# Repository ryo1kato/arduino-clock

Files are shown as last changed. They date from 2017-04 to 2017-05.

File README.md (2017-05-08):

## Arduino Blink "minute repeater" Clock (ATtiny85 version)

A clock with blinking LED indicating the time of day. &nbsp;
LED version of a [repeater](https://en.wikipedia.org/wiki/Repeater_%28horology%29)
You can tell a time in the dark, from distance, w/o glasses. &nbsp;
Useful if you're myopic and don't have glasses or smartphone within reach of your hand when you're in the bed (like me, with my two kids blocking my both sides). &nbsp;
LED brightness is automatically adjusted with light sensor (CdS photo cell)
The design uses AVR ATtiny85 micro controller and DS3231 RTC chip with "smart" RGB LED WS2812B.

## Telling Time
* Blinking in white: base hour of 0, 3, 6, or 9 o'clock.
    - once        : 0 o'clock
    - twice       : 3 o'clock
    - three times : 6 o'clock
    - four times  : 9 o'clock

* Blinking in <span style='color: #00AA00'>**green**</span>: add one or two hours to the above base hour.
    - example: blinking in white for three times, and then twice in green indicates 8 o'clock (8am or 8pm)

* Blinking in <span style='color: red'>**red**</span>: 10 minutes per blink.
    - example: blinking in red for four times: 40 minutes

* Blinking in <span style='color: blue'>**blue**</span>(fast): one minute per blink.

The clock blinks in white -> green -> blue -> blue, skipping some of the colors, for example, skipping red if the time is 10:02 (in which case it blinks in whilte three times, in green once, skips green, and in blue twice)

After completing this cycle, clock sleeps about 3 seconds and start a new cycle.

### Adjusting Time
Long press *Hour* and/or *Minute* button until they start blinking slowly in max brightness.

* Long press *Hour* button : advance time by 60 minutes (blinks in green)
* Long press *Minute* button : advance time by one minutes (blinks in blue)
* Long press **both** buttons : advance time by ten minutes (blinks in red)

You need to keep the buttons pressed and wait for an time indicating cycle to complete, until it starts blinking slowly and brightly.

### Build of Materials
* PCB
    - SMD (rev 0.5.1) [OSH Park](https://oshpark.com/shared_projects/CKZP3omf)
    - THT (rev 0.2) [OSH Park](https://oshpark.com/shared_projects/mC1U04Ox)
* BOM: [bom.txt](schematic/bom.txt)

### Port Assignment
* RST (GPIO #5) - Hour & Minute Buttons (using ADC above 2.2v reset threshold)
* GPIO #0       -  I2C SDA to RTC
* GPIO #1       -  Smart LED NeoPixel WS2812B
* GPIO #2       -  I2C SCL to RTC
* GPIO #3       -  Photo Cell
* GPIO #4       -  Power Control for LED, RTC, Photo Cell

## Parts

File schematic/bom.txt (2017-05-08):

BOM for SMD version (rev 0.5.1) of the board: https://oshpark.com/shared_projects/CKZP3omf
There's an THT version of the board too. https://oshpark.com/shared_projects/mC1U04Ox - Simply chagne C and R to THT versions.

Digi-Key Cart: http://www.digikey.com/short/3nb1p4 (Except WS2812B LED)

SW3   Minute       Panasonic Electronic Components EVQ-PE104K
U1    ATTiny85     ATTINY85-20PU-ND (DIP8)
R2    PHOTO CELL   Photo resister 10~100k ohm @ 10lux
R3    R_ADC        0805(2012 metric) 4.7K ohm, or adjust resistance based on photo cell resistance characteristic
SW2   Hour         Panasonic Electronic Components EVQ-PE104K
R4    10K          0805(2012 metric)
U2    DS3231       DS3231SN (SOIC-16W)
BT1   Battery      Keystone 36-2479-ND
R6    5K           0805(2012 metric) 5K ohm (4.7K ohm works as well)
R5    2K           0805(2012 metric) 2K ohm
J2    WS2812B_OUT  Pin_Headers:Pin_Header_Straight_1x03
J1    ICSP         Pin_Headers:Pin_Header_Straight_2x03
U3    MCP1700T     MCP1700T-3302E/MB (SOT89)
C2    1uF          0805(2012 metric)
C1    1uF          0805(2012 metric)
J3    I2C          Pin_Headers:Pin_Header_Straight_1x04
R7    SCL_PUP      0805(2012 metric) 4.7K ohm
R1    SDA_PUP      0805(2012 metric) 4.7K ohm
LED1  WS2812       WS2812-8mm: Designed for  https://www.adafruit.com/product/1734, but only tested with https://www.amazon.com/dp/B01D1FFVOA
C4    0.1uF        0805(2012 metric)
C5    0.1uF        0805(2012 metric)
C6    0.1uF        0805(2012 metric)
C3    0.1uF (LED)  0805(2012 metric) for WS2812B. You don’t need this when using https://www.amazon.com/dp/B01D1FFVOA

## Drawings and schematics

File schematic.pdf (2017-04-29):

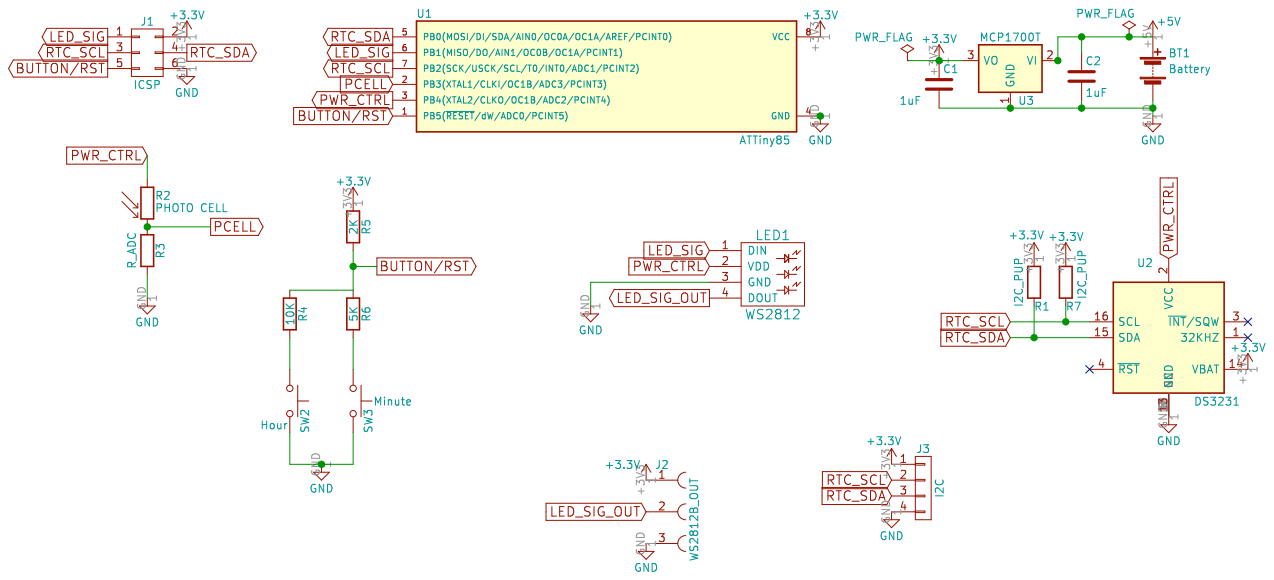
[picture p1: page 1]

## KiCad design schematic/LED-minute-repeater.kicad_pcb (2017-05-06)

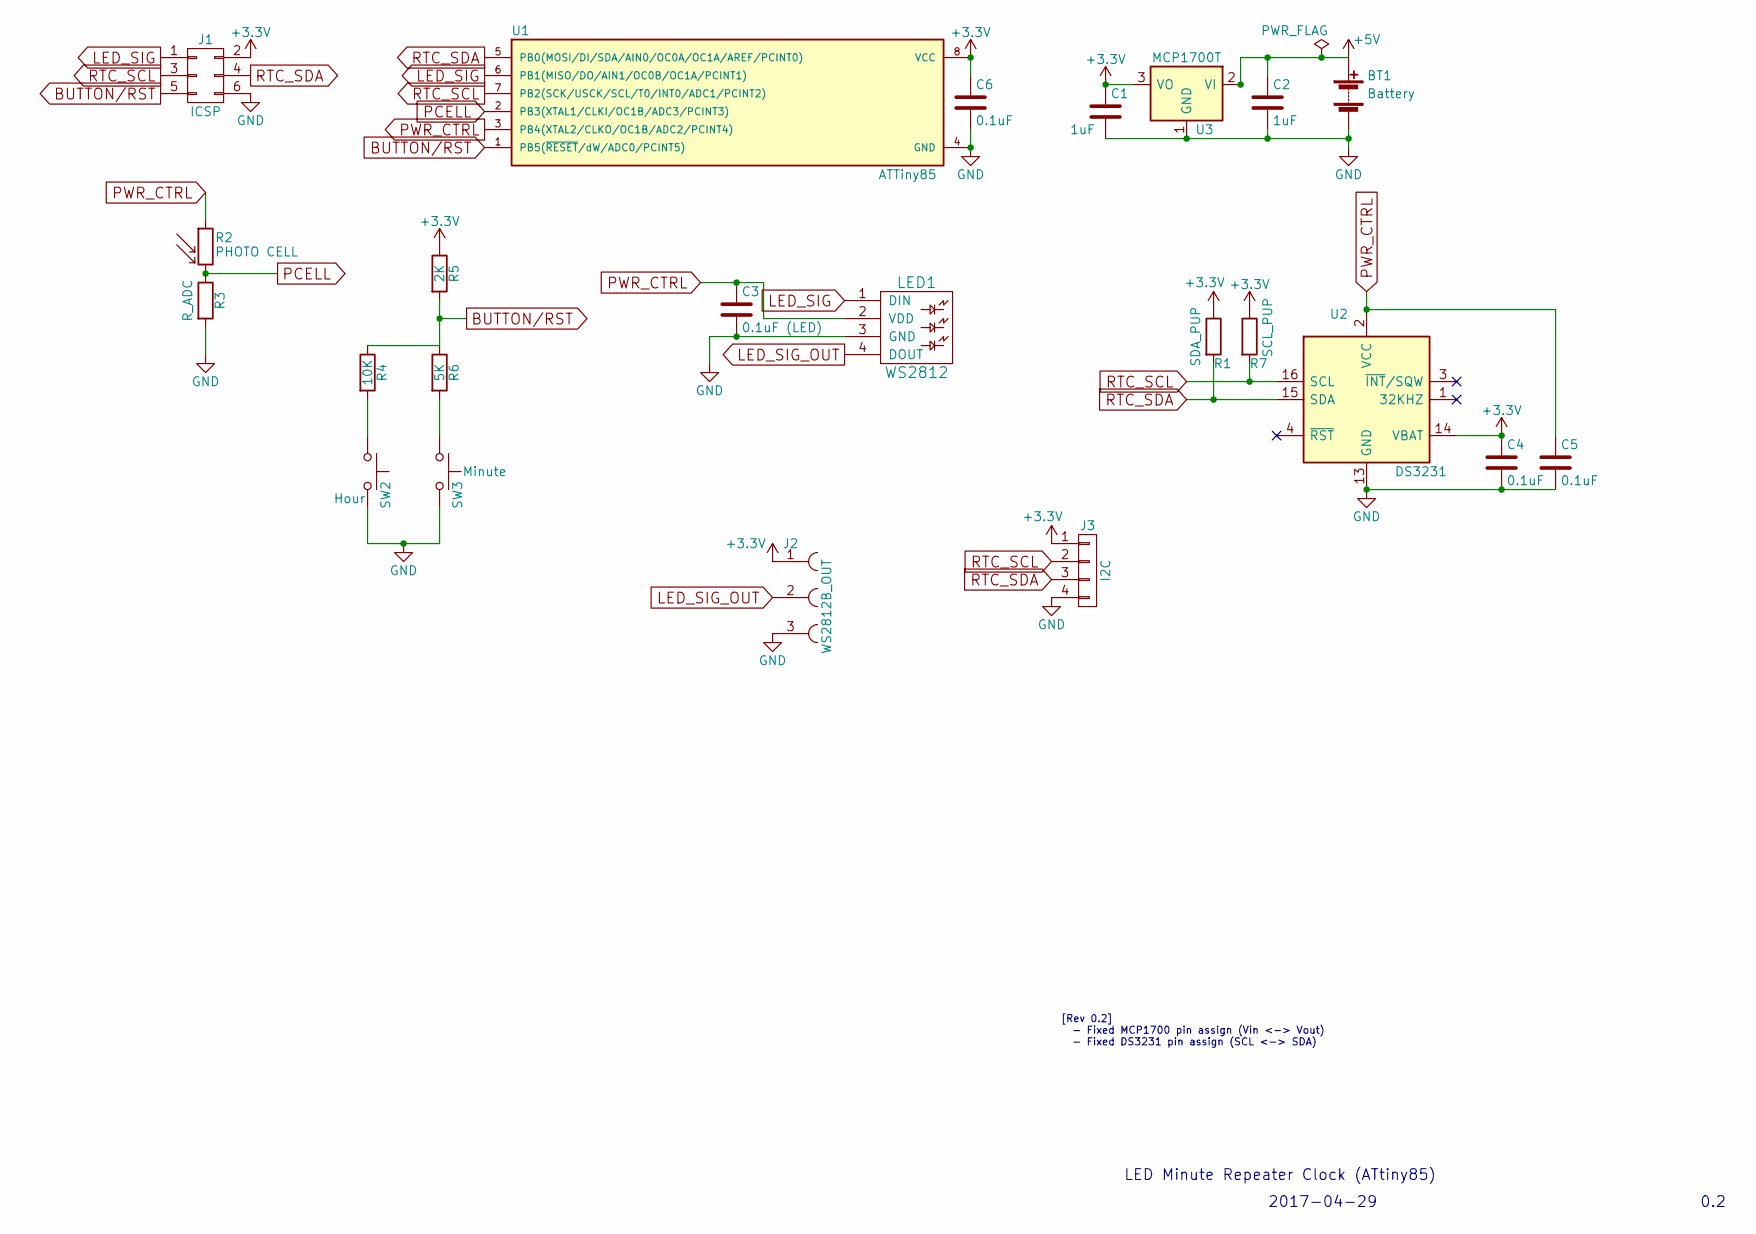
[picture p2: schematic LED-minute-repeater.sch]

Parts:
BT1: Battery; BatteryHolder_3xAAA_Keystone_2479
C1, C2: 1uF; C_0805_HandSoldering
C3: 0.1uF (LED); C_0805_HandSoldering
C4, C5, C6: 0.1uF; C_0805_HandSoldering
J1: ICSP; Pin_Header_Straight_2x03
J2: WS2812B_OUT; Pin_Header_Straight_1x03
J3: I2C; Pin_Header_Straight_1x04
LED1: WS2812; WS2812-8mm
R1: SDA_PUP; R_0805_HandSoldering
R2: PHOTO CELL; Resistor_LDR_4.9x4.2_RM2.54
R3: R_ADC; R_0805_HandSoldering
R4: 10K; R_0805_HandSoldering
R5: 2K; R_0805_HandSoldering
R6: 5K; R_0805_HandSoldering
R7: SCL_PUP; R_0805_HandSoldering
SW2: Hour; SW_SPST_EVQPE1
SW3: Minute; SW_SPST_EVQPE1
U1: ATTiny85; DIP-8_W7.62mm
U2: DS3231; SOIC-16W_7.5x10.3mm_Pitch1.27mm
U3: MCP1700T; SOT89-3_Housing_Handsoldering

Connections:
+3V3: C1.1, C4.1, C6.1, J1.2, J2.1, J3.1, R1.1, R5.1, R7.1, U1.8 (VCC), U2.14 (VBAT), U3.3 (VO)
+5V: BT1.1 (+), C2.1, U3.2 (VI)
BUTTON/RST: J1.5, R4.1, R5.2, R6.1, U1.1 (PB5(~RESET~/dW/ADC0/PCINT5))
GND: BT1.2 (-), C1.2, C2.2, C3.2, C4.2, C5.2, C6.2, J1.6, J2.3, J3.4, LED1.3 (GND), R3.2, SW2.2, SW3.2, U1.4 (GND), U2.5 (NC), U2.6 (NC), U2.7 (NC), U2.8 (NC), U2.9 (NC), U2.10 (NC), U2.11 (NC), U2.12 (NC), U2.13 (GND), U3.1 (GND)
LED_SIG: J1.1, LED1.1 (DIN), U1.6 (PB1(MISO/DO/AIN1/OC0B/OC1A/PCINT1))
LED_SIG_OUT: J2.2, LED1.4 (DOUT)
unnamed: R4.2, SW2.1
unnamed: R6.2, SW3.1
PCELL: R2.2, R3.1, U1.2 (PB3(XTAL1/CLKI/OC1B/ADC3/PCINT3))
PWR_CTRL: C3.1, C5.1, LED1.2 (VDD), R2.1, U1.3 (PB4(XTAL2/CLKO/OC1B/ADC2/PCINT4)), U2.2 (VCC)
RTC_SCL: J1.3, J3.2, R7.2, U1.7 (PB2(SCK/USCK/SCL/T0/INT0/ADC1/PCINT2)), U2.16 (SCL)
RTC_SDA: J1.4, J3.3, R1.2, U1.5 (PB0(MOSI/DI/SDA/AIN0/OC0A/OC1A/AREF/PCI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), U2.15 (SDA)

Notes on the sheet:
2017-04-29
LED Minute Repeater Clock (ATtiny85)
0.2
[Rev 0.2] - Fixed MCP1700 pin assign (Vin <-> Vout) - Fixed DS3231 pin assign (SCL <-> SDA)

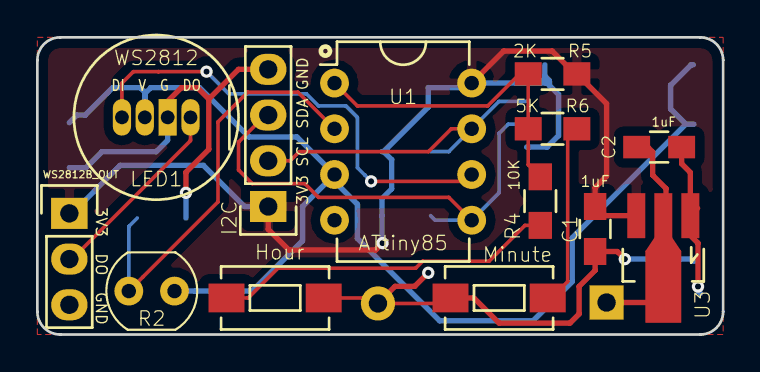
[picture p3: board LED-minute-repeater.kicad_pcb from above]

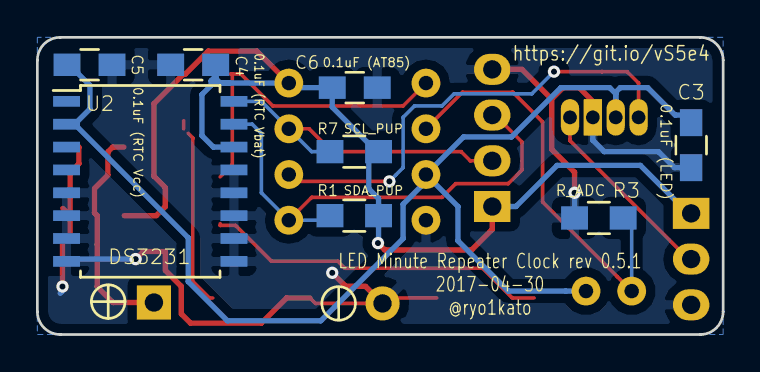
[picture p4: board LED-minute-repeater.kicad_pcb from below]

Board: 2 copper layers, 38.1 x 16.5 mm, 22 parts (9 on the bottom side), 12 nets.

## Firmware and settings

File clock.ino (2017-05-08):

#include <avr/sleep.h>
#include <avr/io.h>
#include <avr/interrupt.h>
#include <avr/common.h>
#include <avr/wdt.h>
#include <avr/sleep.h>

#include <EEPROM.h>
#include <TinyWireM.h>
#include "TinyRTClib.h"
#include "Narcoleptic.h"

#define EEPROM_VOID       123U


///////////////////////////////////////////////////////////////////////////////
//
// Pin Assign
//

// ATTiny85 Analog pins
#define PB2_ANALOG  (1)
#define PB3_ANALOG  (3)
#define PB4_ANALOG  (2)
#define PB5_ANALOG  (0)
#define A0 (5)
#define A1 (2)
#define A2 (4)
#define A3 (3)


// PB0 is SDA for i2c
#define NEOPIXEL_PIN       (1)
// PB2 is SCL for i2c
#define PHOTOCELL_PIN      PB3_ANALOG
#define PWRCTL_PIN         (4)
//#define DEBUG_TX_PIN       (4)
#define BUTTONS_PIN        PB5_ANALOG  // A0 = PB5 = RST


void msleep (uint32_t msecs) {
    Narcoleptic.delay(msecs);
}


///////////////////////////////////////////////////////////////////////////////
//
// Other Configurations
//

#define NUMPIXELS           (1)
#define BAUD             (9600)
#define BLINK_HZ            (3)
#define BRIGHTNESS_BASE    ( 4U) //minimum brightness, PWM 1~255
#define PHOTOCELL_MIN      (50U) //Set LED to min/max intencity if photocell ...
#define PHOTOCELL_MAX     (700U) //...reading is below or above these values
#define BRIGHTNESS_MAX    (128U)

void blink(unsigned char r, unsigned char g, unsigned char b, int count, int hz=BLINK_HZ);

///////////////////////////////////////////////////////////////////////////////
#ifdef NEOPIXEL_PIN
#include <Adafruit_NeoPixel.h>
Adafruit_NeoPixel pixels = Adafruit_NeoPixel(NUMPIXELS, NEOPIXEL_PIN, NEO_RGB + NEO_KHZ800);
#endif

///////////////////////////////////////////////////////////////////////////////
//
// Initialization Codes
//

#ifdef DEBUG_TX_PIN
#define CONFIG_SERIAL_OUTPUT
// See http://forum.arduino.cc/index.php?topic=112013.0
#include <SendOnlySoftwareSerial.h>
SendOnlySoftwareSerial mySerial(DEBUG_TX_PIN);
#define Serial mySerial  //Avoid conflict with the standard ATTinyCore's TinySoftwareSerial
#define debug(fmt, ...) Serial.print(fmt, ##__VA_ARGS__)
#define debugln(fmt, ...) Serial.println(fmt, ##__VA_ARGS__)
#else
#define debug(fmt, ...) /* disappear */
#define debugln(fmt, ...) /* disappear */
#endif //DEBUG_TX_PIN

void setup_powersave () {
    MCUCR |= _BV(BODS) | _BV(BODSE);  //turn off the brown-out detector
    ADCSRA &= ~_BV(ADEN); // disable adc
    ACSR |= _BV(ACD);     //disable the analog comparator
    PRR = bit(PRTIM1);
}


#ifdef PWRCTL_PIN
unsigned int pwrctl_users = 0U;
void setup_powerctl() {
    pinMode(PWRCTL_PIN, OUTPUT);
    digitalWrite(PWRCTL_PIN, LOW);
}
void power_enable () {
    digitalWrite(PWRCTL_PIN, HIGH);
    delay(1);
}
void power_disable () {
    digitalWrite(PWRCTL_PIN, LOW);
}
#else // let them disappear
#   define setup_powerctl()
#   define power_enable()
#   define power_disable()
#endif


RTC_DS3231 rtc;
void setup_rtc() {
    power_enable();
    TinyWireM.begin();
    rtc.begin();
    if (rtc.lostPower()) {
        debug("RTC power lost. Loading from EEPROM: ");
        DateTime saved_time = clock_load();
        debug(saved_time.hour()); debug(":");
        debug(saved_time.minute()); debug(":");
        debugln(saved_time.second());
        rtc.adjust( saved_time );
        delay(200);
        blink(100, 0, 0, 3, 10);
        delay(200);
    } else {
        delay(200);
        blink(0, 100, 0, 3, 10);
        delay(200);
    }
    power_disable();
}



void setup_neopixel () {
#ifdef NEOPIXEL_PIN
    pinMode(NEOPIXEL_PIN, OUTPUT);
    // Walk through colors as a simple initial test
    power_enable();
    pixels.begin();
    pixels.setPixelColor(0, pixels.Color(255, 0, 0));
    pixels.show();
    msleep(300);
    pixels.setPixelColor(0, pixels.Color(0, 255, 0));
    pixels.show();
    msleep(300);
    pixels.setPixelColor(0, pixels.Color(0, 0, 255));
    pixels.show();
    msleep(300);
    pixels.clear();
    pixels.show();
    power_disable();
#endif
}



#ifdef CONFIG_SERIAL_OUTPUT
void setup_serial() {
    Serial.begin(BAUD);
    Serial.println("")
    Serial.println("LED Minute Repeater Clock v0.1")
}
void print_time(bool overwrite = false) {
    power_enable();
    DateTime now = rtc.now();
    power_disable();

    unsigned int y = now.year();
    unsigned int M = now.month();
    unsigned int D = now.day();
    unsigned int h = now.hour();
    unsigned int m = now.minute();
    unsigned int s = now.second();
    if (overwrite) {
        Serial.print("      \r");
    }
    Serial.print(y, DEC);
    Serial.print('-');
    if ( M < 10 ) { Serial.print("0"); }
    Serial.print(M, DEC);
    Serial.print('-');
    if ( D < 10 ) { Serial.print("0"); }
    Serial.print(D, DEC);
    Serial.print(" ");
    Serial.print(h);
    Serial.print(":");
    if ( m < 10 ) { Serial.print("0"); }
    Serial.print(m);
    Serial.print(".");
    if ( s < 10 ) { Serial.print("0"); }
    Serial.print(s);
    if (!overwrite) {
        Serial.println("");
    }


}
#else
#define setup_serial()
#define print_time()
#endif

int analogReadPS(uint8_t pin) {

    ACSR &= ~ _BV(ACD);     // Enablethe analog comparator
    bitClear(PRR, PRADC);   // power up ADC
    ADCSRA |= _BV(ADEN);

    unsigned int reading = analogRead(pin);

    ADCSRA &= ~_BV(ADEN);
    bitSet(PRR, PRADC);     // power down ADC
    ACSR |= _BV(ACD);       //Disable the analog comparator
    return reading;
}

unsigned char brightness()
{
#ifdef PHOTOCELL_PIN
    power_enable();
    unsigned int reading = analogReadPS(PHOTOCELL_PIN);
    unsigned char brightness;
    if ( reading < PHOTOCELL_MIN ) {
        brightness = BRIGHTNESS_BASE;
    } else {
        brightness = BRIGHTNESS_BASE + (BRIGHTNESS_MAX - BRIGHTNESS_BASE)
                    * (reading - PHOTOCELL_MIN)/(PHOTOCELL_MAX - PHOTOCELL_MIN);
    }
    if (brightness >= BRIGHTNESS_MAX ) {
        brightness = BRIGHTNESS_MAX;
    }
    power_disable();
#ifdef CONFIG_SERIAL_OUTPUT
    Serial.print("    ADC value: ");
    Serial.println(reading);
    Serial.print("    Brightness: ");
    Serial.println(brightness);
#endif
    return brightness;
#else
    return BRIGHTNESS_MAX/4;
#endif
}


// Poor man's wear-leveling
unsigned int eeprom_current_slot () {
    for (unsigned int i=0; i < EEPROM.length() ; i++) {
        if ( EEPROM.read(i) < EEPROM_VOID ) {
            return i;
        }
    }
    return 0;
}

void clock_save(uint8_t h, uint8_t m, uint8_t s) {
    /* clear current slot */
    unsigned int offset = eeprom_current_slot();
    EEPROM.write(offset + 0, EEPROM_VOID);
    EEPROM.write(offset + 1, EEPROM_VOID);
    EEPROM.write(offset + 2, EEPROM_VOID);

    offset += 3;
    if (offset + 3 >= EEPROM.length() ) {
        offset = 0;
    }

    EEPROM.write(offset + 0, h);
    EEPROM.write(offset + 1, m);
    EEPROM.write(offset + 2, s);
}

DateTime clock_load() {
    unsigned int offset = eeprom_current_slot();
    unsigned char h = EEPROM.read(offset + 0);
    unsigned char m = EEPROM.read(offset + 1);
    unsigned char s = EEPROM.read(offset + 2);
    return DateTime(2000, 1, 1, h, m, s);
}


void blink(unsigned char r, unsigned char g, unsigned char b, int count, int hz=BLINK_HZ)
{
    for (int i = 0; i < count; i++) {
        power_enable();
        pixels.setPixelColor(0, pixels.Color(g, r, b));
        pixels.setPixelColor(1, pixels.Color(g, r, b));
        pixels.show();
        msleep(1000/hz/2);
        pixels.clear();
        pixels.show();
        power_disable();
        msleep(1000/hz);
    }
}


int last_save_min = 0;
void blink_time() {
    power_enable();
    DateTime now = rtc.now();
    power_disable();
    uint8_t h = now.hour();
    uint8_t m = now.minute();
    uint8_t s = now.second();

    int br = brightness();
    // once -> 0, twice -> 3, tri -> 6, quad -> 9 o'clock
    blink(br, br, br, (h%12) / 3 + 1);
    msleep(1000/BLINK_HZ);

    //hour
    blink(0, br, 0, (h%12) % 3);
    msleep(1000/BLINK_HZ);

    //ten minutes
    blink(br, 0, 0, m / 10 );
    msleep(2*1000/BLINK_HZ);

    //last digit of minutes
    blink(0, 0, br, m % 10, BLINK_HZ*2);
    msleep(2*1000/BLINK_HZ);

    if (last_save_min != m) {
        clock_save(h, m, s);
        last_save_min = m;
    }

}


int readButtons() {
    unsigned int reading = analogReadPS(BUTTONS_PIN);
    debug("    Button ADC: ");
    debugln(reading);
    if (reading > 950) {
        return 0;  // 2K ohm pullup
    }
    else if (reading > 800) {
        return 1;  //10K ohm button
    }
    else if (reading > 700) {
        return 2;  // 5k ohm button
    }
    else {
        return 3;  // both 10k and 5k ohm, composite resistance =
    }
}

bool buttonHour(unsigned int buttonStatus) {
    return ( (buttonStatus & 0x01) > 0 );
}
bool buttonMinute(unsigned int buttonStatus) {
    return ( (buttonStatus & 0x02) > 0 );
}

void advanceRtcMinutes(int minutes) {
    power_enable();
    DateTime now = rtc.now();
    DateTime adj = DateTime( now.unixtime() + (minutes*60) );
    rtc.adjust( adj );
    power_disable();
}


void setup() {
    setup_powersave();
    setup_serial();
    setup_powerctl();
    setup_neopixel();
    setup_rtc();
}


void loop() {
    print_time();
    blink_time();

    int btn = readButtons();
    while ( btn > 0 ) {
        if ( buttonHour(btn) && buttonMinute(btn) ) {
            blink(0, BRIGHTNESS_MAX, 0, 1, 2);
            advanceRtcMinutes(10);
        }
        else if ( buttonHour(btn) ) {
            blink(BRIGHTNESS_MAX, 0, 0, 1, 2);
            advanceRtcMinutes(60);
        }
        else if ( buttonMinute(btn) ) {
            blink(0, 0, BRIGHTNESS_MAX, 1, 2);
            advanceRtcMinutes(1);
        }
        print_time();
        btn = readButtons();
    }

    msleep(2000);
}

;

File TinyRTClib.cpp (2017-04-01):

// Code by JeeLabs http://news.jeelabs.org/code/
// Released to the public domain! Enjoy!
// Adafruit modifications for Aradruit DS3231 breakout
//  board Product 268, Arduino Due and Trinket/Gemma

#include <avr/pgmspace.h>
#include <TinyWireM.h>
#define WIRE TinyWireM
#include "TinyRTClib.h"

#define DS3231_ADDRESS 0x68
#define DS3231_CONTROL  0x0E
#define DS3231_STATUSREG 0x0F

// Control Register bits
#define DS3231_EN32kHz (3)

#define SECONDS_PER_DAY 86400L

#define SECONDS_FROM_1970_TO_2000 946684800

#include <Arduino.h>


static uint8_t read_i2c_register(uint8_t addr, uint8_t reg) {
  WIRE.beginTransmission(addr);
  WIRE.write(reg);
  WIRE.endTransmission();

  WIRE.requestFrom(addr, (byte)1);
  return WIRE.read();
}

static void write_i2c_register(uint8_t addr, uint8_t reg, uint8_t val) {
  WIRE.beginTransmission(addr);
  WIRE.write(reg);
  WIRE.write(val);
  WIRE.endTransmission();
}



////////////////////////////////////////////////////////////////////////////////
// utility code, some of this could be exposed in the DateTime API if needed

const uint8_t daysInMonth [] PROGMEM = { 31,28,31,30,31,30,31,31,30,31,30,31 };

// number of days since 2000/01/01, valid for 2001..2099
static uint16_t date2days(uint16_t y, uint8_t m, uint8_t d) {
    if (y >= 2000)
        y -= 2000;
    uint16_t days = d;
    for (uint8_t i = 1; i < m; ++i)
        days += pgm_read_byte(daysInMonth + i - 1);
    if (m > 2 && y % 4 == 0)
        ++days;
    return days + 365 * y + (y + 3) / 4 - 1;
}

static long time2long(uint16_t days, uint8_t h, uint8_t m, uint8_t s) {
    return ((days * 24L + h) * 60 + m) * 60 + s;
}

////////////////////////////////////////////////////////////////////////////////
// DateTime implementation - ignores time zones and DST changes
// NOTE: also ignores leap seconds, see http://en.wikipedia.org/wiki/Leap_second

DateTime::DateTime (uint32_t t) {
  t -= SECONDS_FROM_1970_TO_2000;    // bring to 2000 timestamp from 1970

    ss = t % 60;
    t /= 60;
    mm = t % 60;
    t /= 60;
    hh = t % 24;
    uint16_t days = t / 24;
    uint8_t leap;
    for (yOff = 0; ; ++yOff) {
        leap = yOff % 4 == 0;
        if (days < 365U + leap)
            break;
        days -= 365 + leap;
    }
    for (m = 1; ; ++m) {
        uint8_t daysPerMonth = pgm_read_byte(daysInMonth + m - 1);
        if (leap && m == 2)
            ++daysPerMonth;
        if (days < daysPerMonth)
            break;
        days -= daysPerMonth;
    }
    d = days + 1;
}

DateTime::DateTime (uint16_t year, uint8_t month, uint8_t day, uint8_t hour, uint8_t min, uint8_t sec) {
    if (year >= 2000)
        year -= 2000;
    yOff = year;
    m = month;
    d = day;
    hh = hour;
    mm = min;
    ss = sec;
}

static uint8_t conv2d(const char* p) {
    uint8_t v = 0;
    if ('0' <= *p && *p <= '9')
        v = *p - '0';
    return 10 * v + *++p - '0';
}

// A convenient constructor for using "the compiler's time":
//   DateTime now (__DATE__, __TIME__);
// NOTE: using PSTR would further reduce the RAM footprint
DateTime::DateTime (const char* date, const char* time) {
    // sample input: date = "Dec 26 2009", time = "12:34:56"
    yOff = conv2d(date + 9);
    // Jan Feb Mar Apr May Jun Jul Aug Sep Oct Nov Dec
    switch (date[0]) {
        case 'J':
            if ( date[1] == 'a' ) {
                m = 1;
            } else if ( date[2] == 'n' ) {
                m = 6;
            } else {
                m = 7;
            }
            break;
        case 'F': m = 2; break;
        case 'A': m = date[2] == 'r' ? 4 : 8; break;
        case 'M': m = date[2] == 'r' ? 3 : 5; break;
        case 'S': m = 9; break;
        case 'O': m = 10; break;
        case 'N': m = 11; break;
        case 'D': m = 12; break;
    }
    d = conv2d(date + 4);
    hh = conv2d(time);
    mm = conv2d(time + 3);
    ss = conv2d(time + 6);
}

uint8_t DateTime::dayOfWeek() const {
    uint16_t day = date2days(yOff, m, d);
    return (day + 6) % 7; // Jan 1, 2000 is a Saturday, i.e. returns 6
}

uint32_t DateTime::unixtime(void) const {
  uint32_t t;
  uint16_t days = date2days(yOff, m, d);
  t = time2long(days, hh, mm, ss);
  t += SECONDS_FROM_1970_TO_2000;  // seconds from 1970 to 2000

  return t;
}

long DateTime::secondstime(void) const {
  long t;
  uint16_t days = date2days(yOff, m, d);
  t = time2long(days, hh, mm, ss);
  return t;
}

////////////////////////////////////////////////////////////////////////////////
// RTC_DS3231 implementation

static uint8_t bcd2bin (uint8_t val) { return val - 6 * (val >> 4); }
static uint8_t bin2bcd (uint8_t val) { return val + 6 * (val / 10); }

uint8_t RTC_DS3231::begin(void) {
    TinyWireM.begin();
    uint8_t reg = read_i2c_register(DS3231_ADDRESS, DS3231_STATUSREG);
    reg &= ~_BV(DS3231_EN32kHz); //disable 32kHz to save power.
    write_i2c_register(DS3231_ADDRESS, DS3231_STATUSREG, reg);
    return 1;
}


bool RTC_DS3231::lostPower(void) {
    return (read_i2c_register(DS3231_ADDRESS, DS3231_STATUSREG) >> 7);
}

void RTC_DS3231::adjust(const DateTime& dt) {
    WIRE.beginTransmission(DS3231_ADDRESS);
    WIRE.write(0);
    WIRE.write(bin2bcd(dt.second()));
    WIRE.write(bin2bcd(dt.minute()));
    WIRE.write(bin2bcd(dt.hour()));
    WIRE.write(bin2bcd(0));
    WIRE.write(bin2bcd(dt.day()));
    WIRE.write(bin2bcd(dt.month()));
    WIRE.write(bin2bcd(dt.year() - 2000));
    WIRE.write(0);
    WIRE.endTransmission();

    uint8_t statreg = read_i2c_register(DS3231_ADDRESS, DS3231_STATUSREG);
    statreg &= ~0x80; // flip OSF bit
    write_i2c_register(DS3231_ADDRESS, DS3231_STATUSREG, statreg);

}

DateTime RTC_DS3231::now() {
  WIRE.beginTransmission(DS3231_ADDRESS);
  WIRE.write(0);
  WIRE.endTransmission();

  WIRE.requestFrom(DS3231_ADDRESS, 7);
  uint8_t ss = bcd2bin(WIRE.read() & 0x7F);
  uint8_t mm = bcd2bin(WIRE.read());
  uint8_t hh = bcd2bin(WIRE.read());
  WIRE.read();
  uint8_t d = bcd2bin(WIRE.read());
  uint8_t m = bcd2bin(WIRE.read());
  uint16_t y = bcd2bin(WIRE.read()) + 2000;

  return DateTime (y, m, d, hh, mm, ss);
}

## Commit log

2017-03-05 first working version with LED blink + eeprom
2017-03-06 add schematics
    [clock.sch]
2017-03-19 fix compile error for Uno/nano
    [clock.ino]
2017-03-21 use photocell for nano boards
2017-04-01 ADC power save
2017-04-01 diable RTC 32Khz, fix compiler warning
    [TinyRTClib.cpp]
2017-04-09 replace delay() with msleep() for clarity
    [clock.ino]
2017-04-15 update schematic
    [LED-minute-repeater.kicad_pcb, LED-minute-repeater.sch, clock.sch]
2017-04-15 fix I2C header silk position
    [LED-minute-repeater.kicad_pcb]
2017-04-15 schematic: fix DS3231 silk
    [LED-minute-repeater.kicad_pcb]
2017-04-29 fix reg and RTC chip pin assign swap
    [LED-minute-repeater.kicad_pcb, LED-minute-repeater.sch]
2017-04-29 PCB layout for rev 0.2 circuit
    [LED-minute-repeater.kicad_pcb, LED-minute-repeater.sch]
2017-05-01 Smaller size SMD version of PCB
    OSH Order #MdFUZar9
    Erratta:
    - I2C GND is not connected
    - Reg (MCP1700) GND is not connected
    [LED-minute-repeater.kicad_pcb, LED-minute-repeater.sch]
2017-05-06 rev 0.5.1 - errata fix for rev0.5
    [LED-minute-repeater.kicad_pcb]
2017-05-08 add bom.txt and update README
